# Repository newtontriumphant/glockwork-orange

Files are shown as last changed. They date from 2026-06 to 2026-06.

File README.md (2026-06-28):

# _Glockwork Orange_, by zsharpminor

A "Clockwork Orange" is defined as a human being who has had their free will and moral agency mechanically stripped away, turning them into a predictable, unthinking mechanism controlled by outside forces like the state. The human's natural "juicy" state is manifest in the orange, whereas the clockwork represents the unnaturality and cold predictability of the system.

Anyways, enough 1984; hiya! I'm Udo, better known as @zsharpminor or gh/newtontriumphant, and I have a thing for self-playing instruments. In late 2025, I won Honorable Mention at Hack Club x AMD's _Prototype_ flagship hackathon with [FiddleStein](https://github.com/newtontriumphant/Hackclub_Prototype_Fiddlestein), a fully self-playing violin that utilized a SO-101 robot arm and a 10k-step neural network to imitate a real human arm playing violin. FiddleStein was a great concept, but it sounded _mildly bad_, to be polite. Ever since early 2026, I wanted to create another self-playing instrument that would fit in well with FiddleStein, and Glockwork Orange was the logical next step.

## About Glockwork Orange

Glockwork Orange is a fully self-playing chromatic Glockenspiel that relies on solenoids to play ANY midi file payload by adjusting the instrumentation to fit into two voices!

> Sidenote: in the musical percussion and orchestra community, "glock" is used to abbreviate "glockenspiel" and is in no way related to the firearm brand created by Gaston Glock.

Glockwork Orange was designed for [Hack Club Outpost](https://outpost.hackclub.com/) as an X-Tier project, and is [on the list of X-Tier approved projects](https://docs.google.com/document/d/1faTrnYnGDMR5YSOkvKIAk_NsVOftPFZkB7XtJXA-l8c/edit?tab=t.0) sent out by [@CAN](https://hackclub.slack.com/archives/C0B519PGU22/p1781193322652829?thread_ts=1781016229.290339&cid=C0B519PGU22).

Anyways, enough yapping. A picture plays more than a thousand notes, or however the saying goes. Feast your eyes on the final assembled mockup of Glockwork Orange below.

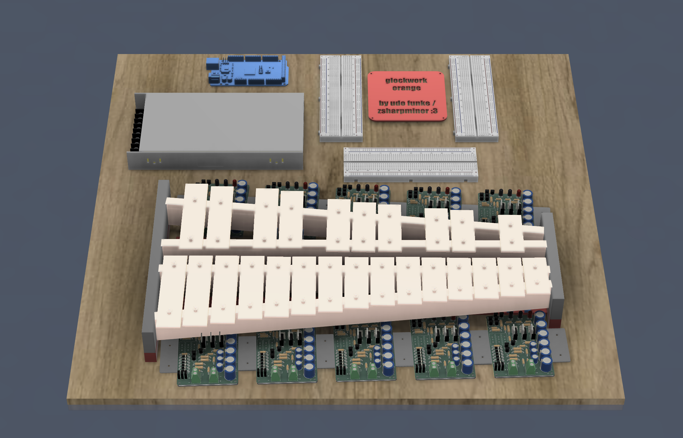
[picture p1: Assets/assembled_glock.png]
Assembled Glock

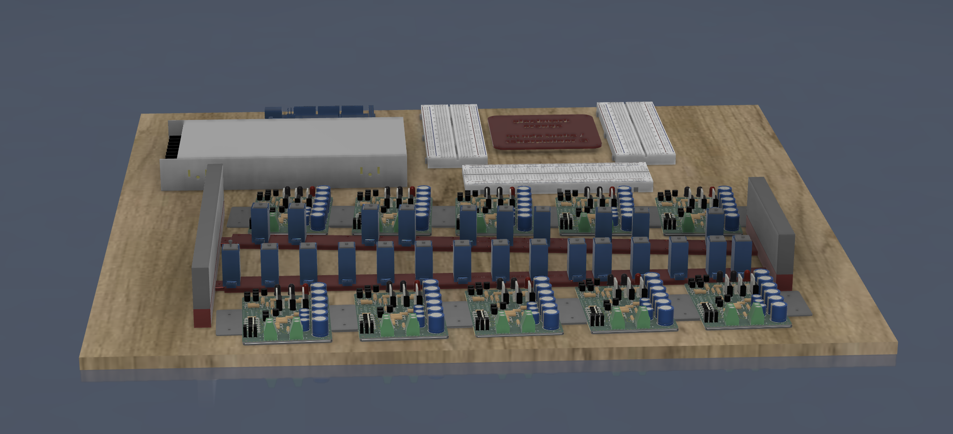
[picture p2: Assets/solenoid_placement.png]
Solenoid Placement


---

At this point, you're probably asking: **how does this lie-detector-looking-thing work?!&**

Well, it's quite simple.

1. The Arduino sends a logic signal to the PCB being striked.
2. The power supply pushes out 15V and routes it into the PCB chain.
3. The respective PCB converts that signal to the current and voltage required to operate the solenoids.
4. The MOSFET briefly powers the solenoid and, by extension, the LED.
5. The solenoid strikes the key and immediately retracts.
6. Repeat (but don't rinse. handwashing is very bad when it comes to PCBs)!

## The PCB

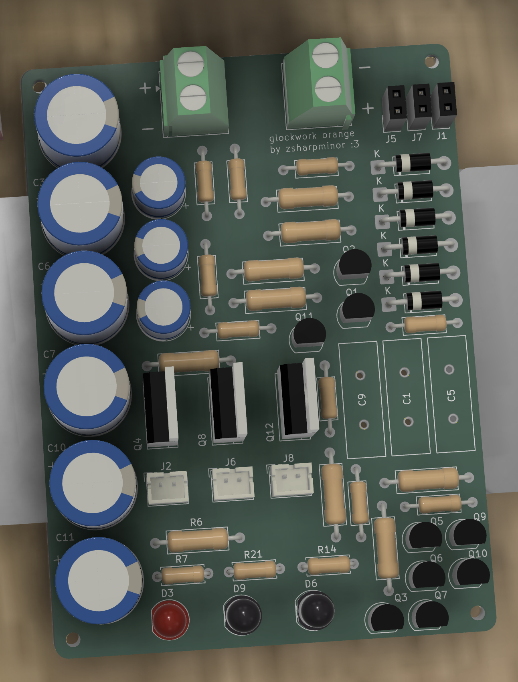
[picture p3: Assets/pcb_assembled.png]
The Assembled PCB


Glockwork Orange's PCB uses a clever arrangement of transistors, resistors, capacitors, and a MOSFET to power the white JST connectors and their respective fading red LEDs each time the individual MOSFET is triggered.

Oh? What do I hear? You're wondering how this monstrosity was wired? If you have any experience doing ground planes on PCBs, I'd recommend you avert your eyes.

fpcb

I've also included an image of the PCB's schematic:

schemfinal

The way this schematic works is by dividing the three inputs from the Arduino into segments, which each result in one JST connector and LED being powered at one time.

## The CAD

The way this project works is that it relies on the individual components being screwed down into a plywood project panel with M2 screws. That's why there's M2 screws on EVERY SINGLE COMPONENT in my CAD folder. 

For more information, including images and in-progress screenshots of every single CAD part, refer to [JOURNAL.md](JOURNAL.md). I won't entirely leave you hanging, though. Here's a side-view:

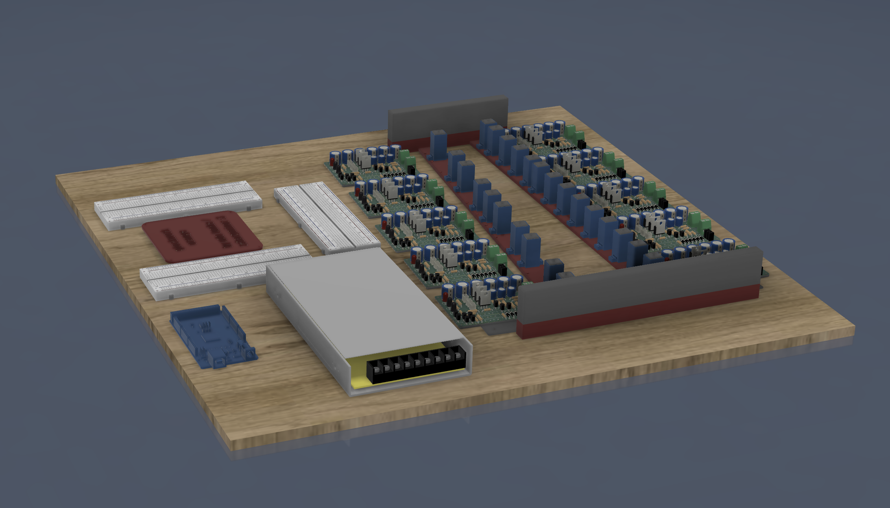
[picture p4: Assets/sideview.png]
side view of glock Side View of Glockwork Orange


The blue parts are the solenoid holders I designed, and they slot onto the red holder bar that I also designed. The grey parts inside the blue holders refer to the actual solenoids.

## Wiring Diagram

Please excuse ~~my dear aunt sally~~ the sloppy wiring, this is only supposed to be *representative* of the final wiring!

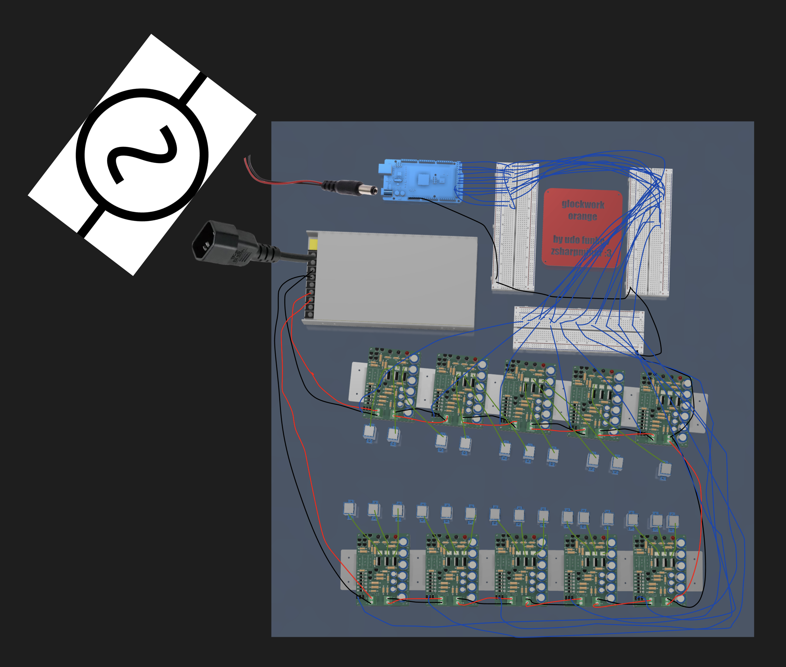
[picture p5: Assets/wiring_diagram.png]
wiring diagram Wiring Diagram


```
+15V --> Red
Shared GND --> Black
Solenoid +/- --> Green
Arduino Signal --> Blue
```

## Firmware

The Glockwork Orange firmware consists of two files: `glockwork_orange.ino`, which runs on the Arduino Mega 2560 and maps all 25 chromatic keys (G2–A4, MIDI 43–69) to digital pins 22–46 driving the IRLZ44N MOSFET gate lines, and `glockwork_host.py`, a Python/Tkinter desktop GUI that parses any MIDI file, re-voices it into two chromatic voices within the glockenspiel's range via octave-shifting, and streams precisely-timed strike commands over USB serial at 115200 baud. The Arduino firmware uses a non-blocking 32-slot ring buffer to schedule and execute 35ms solenoid pulses without any delay() calls, which means the timing is, dare I say so myself, quite accurate across simultaneous voices. The host communicates via a simple ASCII protocol (S to start, N{ms},{note} to schedule a strike, X to stop), making it straightforward to extend or replace the Python frontend with any serial-capable environment.

## The Why And The How

Why did I make Glockwork Orange? Well, this one's pretty simple. I always wanted to make a successor to FiddleStein, one that could permanently work and be mounted in place with actual PCBs rather than precarious wiring and hot glue. (Also, using it to get into Outpost was a pretty fun motivation!)

How did I make Glockwork Orange? The entire process is in [JOURNAL.md](JOURNAL.md). Go read it. No, seriously. A lot of research went into this project, and it's a culmination of thoughts and solenoids. TL;DR, the answer is Patience (and a lack thereof).

## Directory

```
.
├── Assets/ <-- Some of the most important images found in this README
├── CAD/ <-- All CAD source files, as well as a .f3z Archive
├── Firmware/ <-- Simple firmware for the Arduino
├── PCB/ <-- KiCad source files of the PCB, .STEP export of PCB
├── Production/ <-- Gerber files and zipped Gerber files
├── BOM.csv <-- All components required to build this monstrosity
├── JOURNAL.md <-- Detailed explanation and tracking of hours
└── README.md <-- This file!
```

## Mini BOM

**NOTE**: The full BOM is located at [BOM.csv](BOM.csv). PLEASE READ IT. THIS IS ONLY A BREAKDOWN.

**CART SCREENSHOTS** can be found in the [Assets/Cart-Screenshots](Assets/Cart-Screenshots/Digikey_Cart_Final.png) folder. PII has been redacted. If the originals are required, DM @zsharpminor on the Hack Club Slack.

| Item | Total | Link |
| :--- | ---: | :---: |
| DigiKey Components | $480.00 | [↗](BOM.csv) |
| Amazon Components | $122.00 | [↗](BOM.csv) |
| Plywood from THD | $15.00 | [↗](BOM.csv) |
| JLCPCB PCB x 10 | $15.00 | [↗](BOM.csv) |
| Arduino and PSU | **OWNED** | - |
| | **$632.00** | |

## Disclosure of AI Usage

No Artificial Intelligence was used in creating the PCB, Schematic, any of the CAD, or README / JOURNAL.

AI was solely used to automate placing links into the BOM (~10% of BOM tracked hours), and for minor assistance with the code (see bottom of [JOURNAL.md](JOURNAL.md) for additional information), and for creating a custom footprint for an obsolete capacitor.

## License

GNU General Public License (GPL)

---

Thanks for reading down all this way! If you have any questions, please reach out to me via the Hack Club Slack @zsharpminor

Made with ♡ by zsharpminor

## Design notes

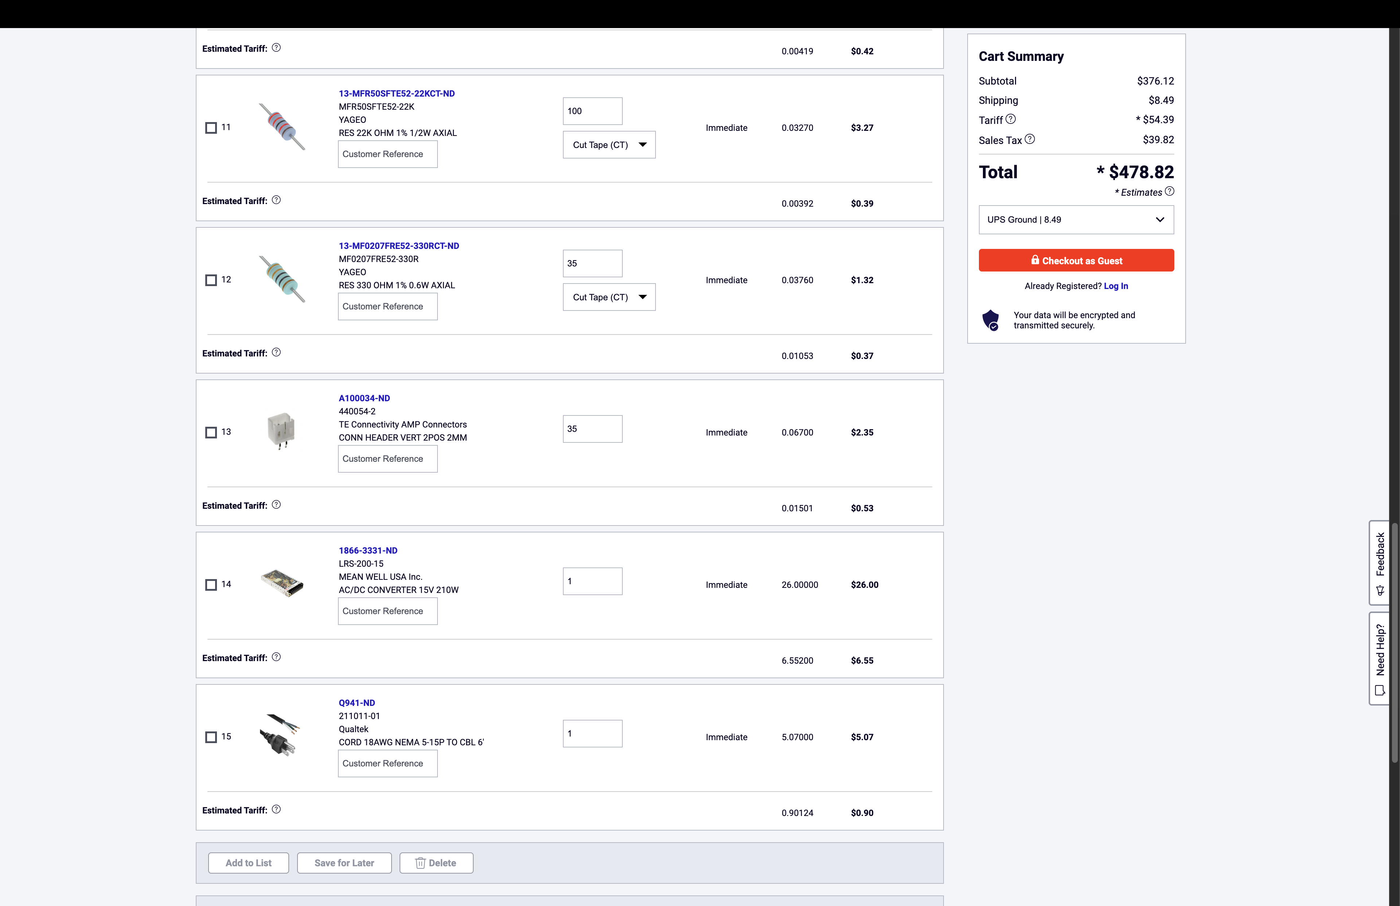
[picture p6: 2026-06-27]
Assets/Cart-Screenshots/Digikey_Cart_3.png

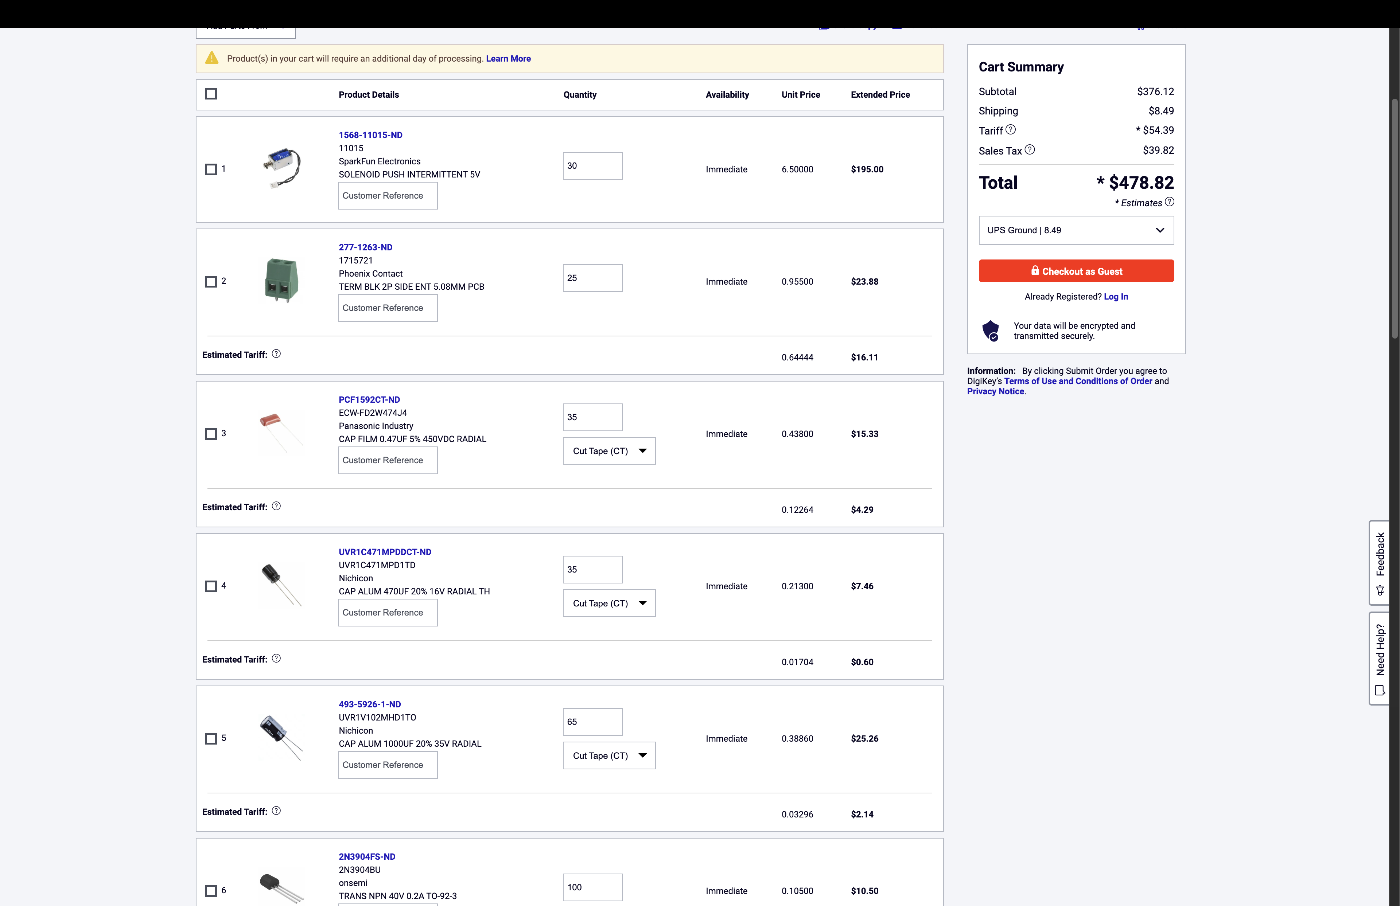
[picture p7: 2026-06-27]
Assets/Cart-Screenshots/Digikey_Cart_1.png

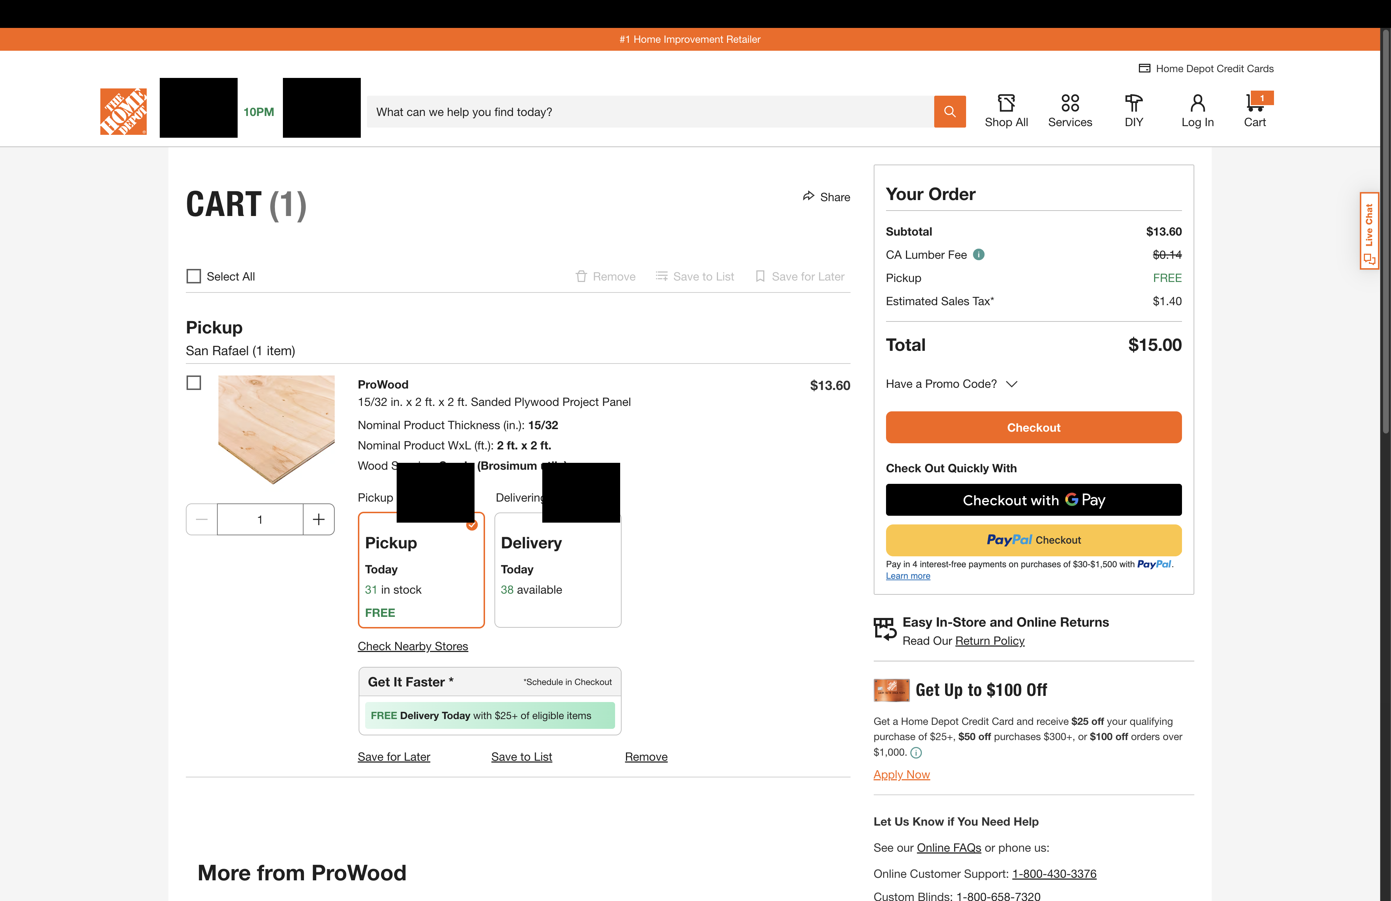
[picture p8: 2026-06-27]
Assets/Cart-Screenshots/The_Home_Depot_Cart.png

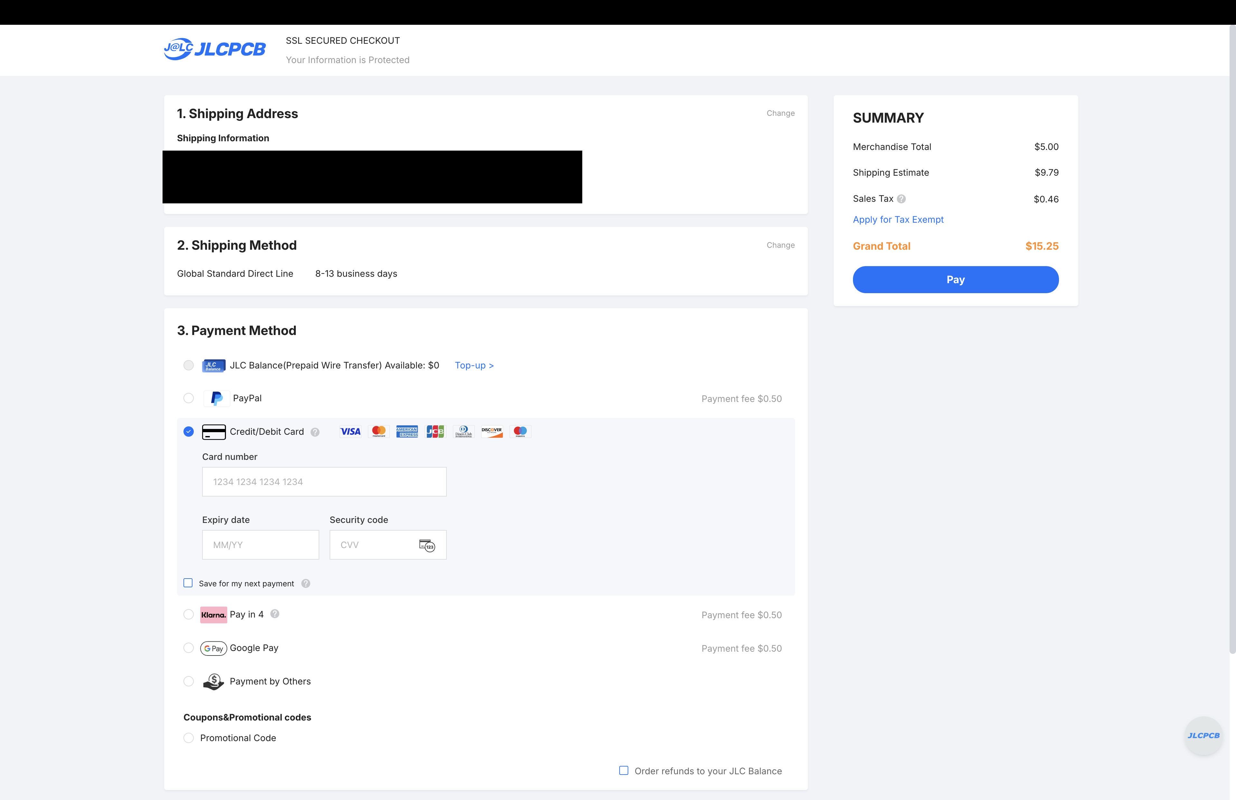
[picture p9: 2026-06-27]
Assets/Cart-Screenshots/JLC_Cart_1.png

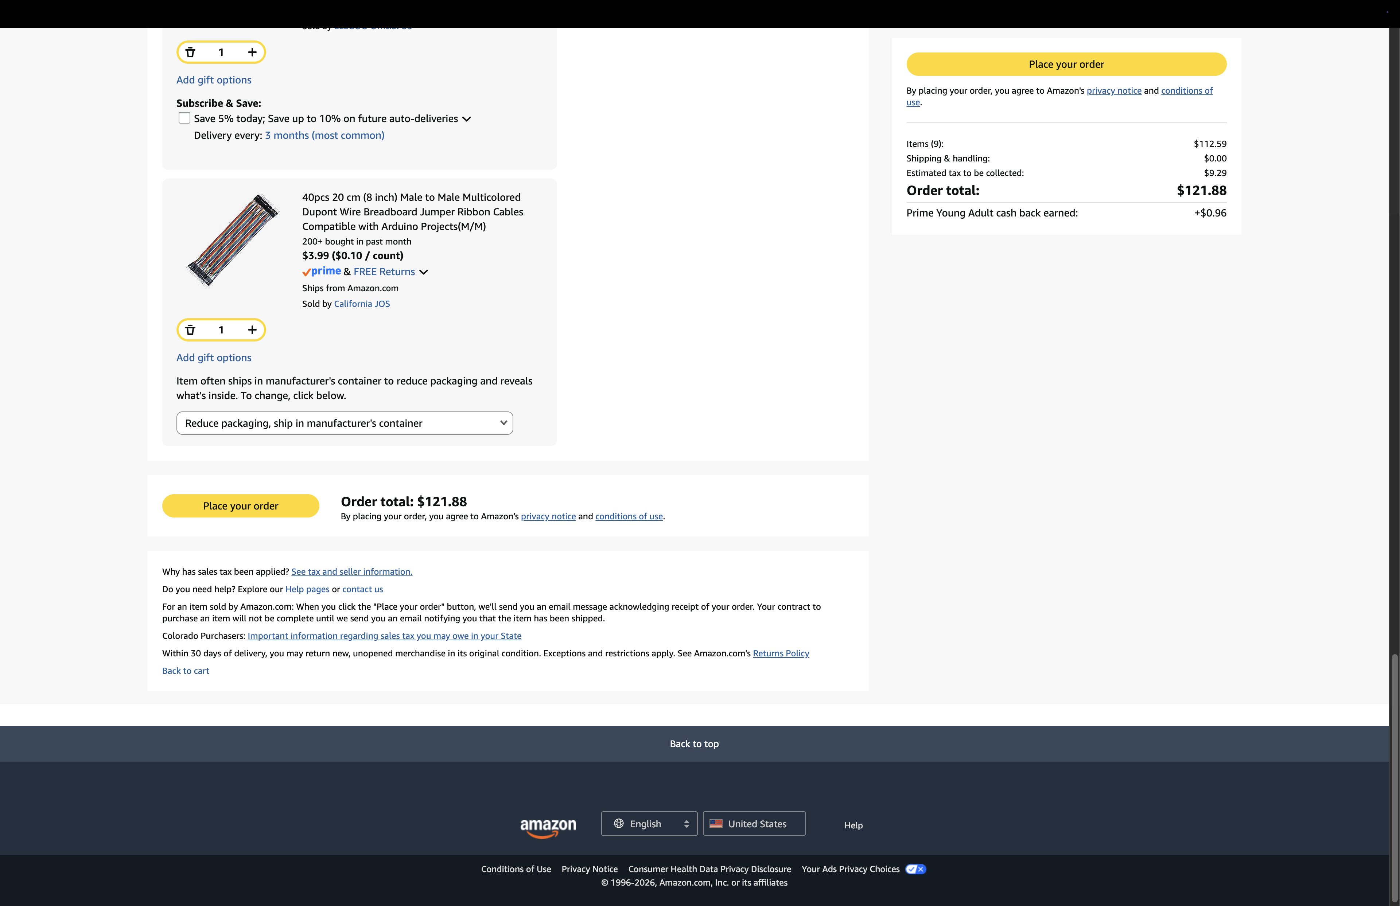
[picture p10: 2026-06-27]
Assets/Cart-Screenshots/Amazon_Cart_1.png

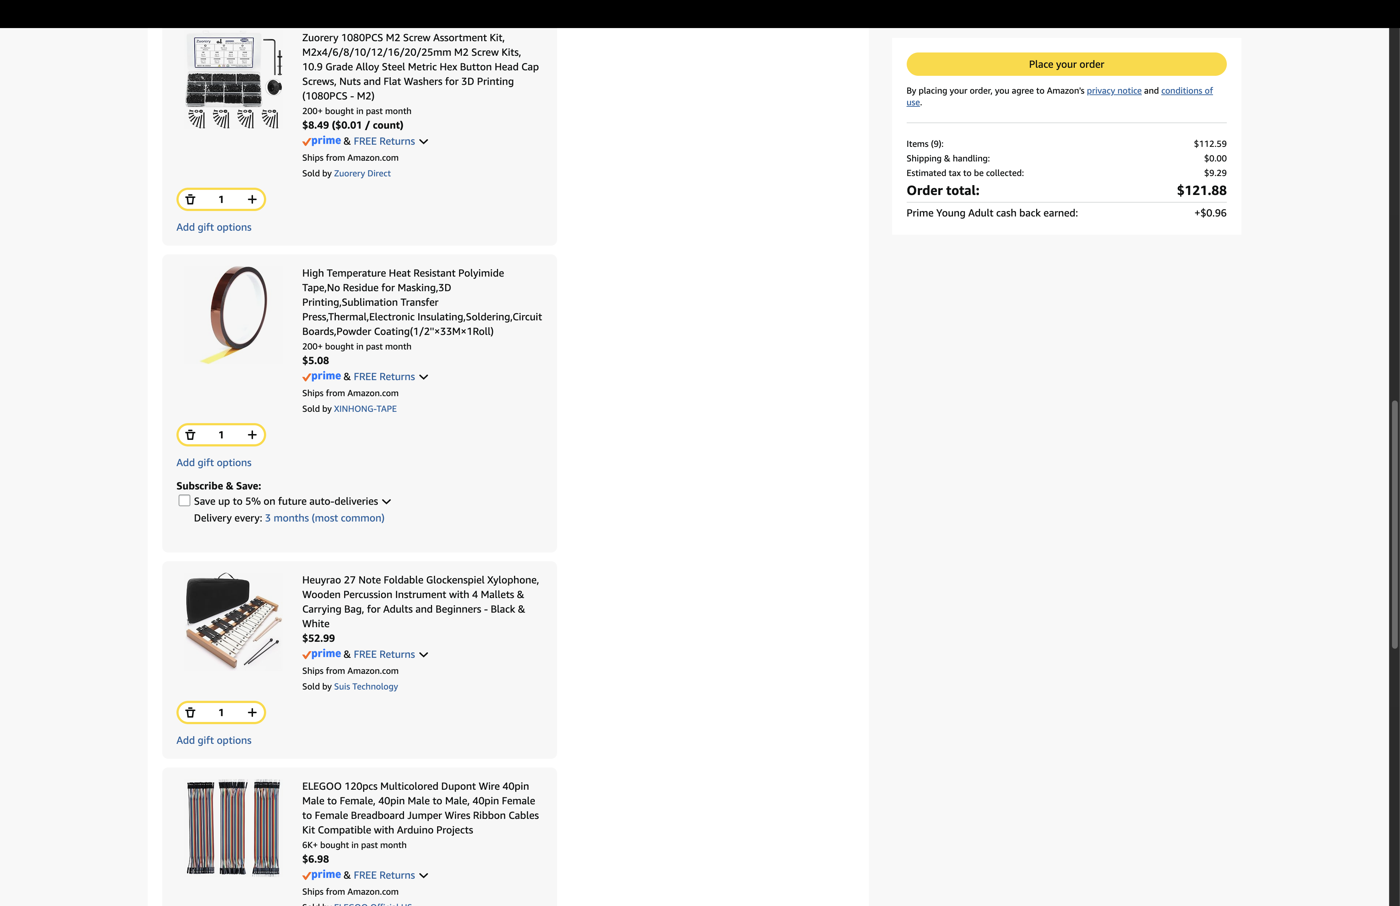
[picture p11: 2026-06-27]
Assets/Cart-Screenshots/Amazon_Cart_2.png

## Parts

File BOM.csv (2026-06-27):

Name | Source | Purpose | Cost Per | Quantity | Cost Total | Link
Terminal Block | Digikey | Input and Output for 15V + GND | $0.96 | 25 | $23.88 | https://www.digikey.com/en/products/detail/phoenix-contact/1715721/260631
5V Solenoid - Small | Digikey | The Glock Actuator | $6.50 | 30 | $195.00 | https://www.digikey.com/en/products/detail/sparkfun-electronics/ROB-11015/6163694
470nF Cap | Digikey | Capacitance | $0.44 | 35 | $15.33 | https://www.digikey.com/en/products/detail/panasonic-electronic-components/ECW-FD2W474J4/3844529
470uF Cap | Digikey | Capacitance | $0.21 | 35 | $7.46 | https://www.digikey.com/en/products/detail/nichicon/UVR1C471MPD1TD/3438545
1000uF Cap | Digikey | Capacitance | $0.39 | 65 | $25.29 | https://www.digikey.com/en/products/detail/nichicon/UVR1V102MHD1TO/3438559
2N3904BU | Digikey | Transistor | $0.11 | 100 | $10.50 | https://www.digikey.com/en/products/detail/onsemi/2N3904BU/1413
1N4007 | Digikey | Rectifier Diode - Current Backtrack Prevention | $0.05 | 100 | $5.40 | https://www.digikey.com/en/products/detail/diotec-semiconductor/1N4007/18833652
LED | Digikey | Diffused Red LED for Showcase Purposes | $0.15 | 35 | $5.08 | https://www.digikey.com/en/products/detail/kingbright/WP7113ID/1747663
MOSFET | Digikey | Toggling On High Current | $0.94 | 50 | $46.95 | https://www.digikey.com/en/products/detail/infineon-technologies/IRLZ44NPBF/811808
Resistor 2.2k | Digikey | Resistance | $0.03 | 100 | $3.30 | https://www.digikey.com/en/products/detail/yageo/MFR50SFTE52-2K2/9151337
Resistor 22k | Digikey | Resistance | $0.03 | 100 | $3.30 | https://www.digikey.com/en/products/detail/yageo/MFR50SFTE52-22K/9151275
Resistor 330 | Digikey | Resistance | $0.04 | 35 | $1.33 | https://www.digikey.com/en/products/detail/yageo/MF0207FRE52-330R/9124999
Solenoid Connector | Digikey | JST Connector for Solenoid | $0.07 | 35 | $2.35 | https://www.digikey.com/en/products/detail/te-connectivity-amp-connectors/440054-2/2077939
Power Cord | Digikey | Scary Wall Outlet ⟶ 3 cables | $5.07 | 1 | $5.07 | https://www.digikey.com/en/products/detail/qualtek/211011-01/5639882
Power Supply | Digikey | AC-DC 15V 210W (PSU) | $26.00 | 1 | $26.00 | https://www.digikey.com/en/products/detail/mean-well-usa-inc/LRS-200-15/7705023
Shipping | Digikey | FedEx Ground | $8.49 | 1 | $8.49 | https://www.digikey.com/ordering/shoppingcart
Tariff | Digikey | US Import Tariff (Estimated) | $54.39 | 1 | $54.39 | https://www.digikey.com/ordering/shoppingcart
Sales Tax | Digikey | I don’t want the IRS to send a bomb to my house /j | $39.82 | 1 | $39.82 | https://www.digikey.com/ordering/shoppingcart
 |  |  |  | subtotal: | $478.92
 |  |  |  | DIGIKEY BOM TOTAL: | $480.00
Arduino Mega 2560 | OWNED | The brains of the project! :D | N/A | 1 | N/A | OWNED
PSU for Arduino | OWNED | Power Supply For The Brain! | N/A | 1 | N/A | OWNED
Full Wood Glockenspiel | Amazon | It Loves Being Hit! Just like your mo- bad joke, sorry. | $52.99 | 1 | $52.99 | https://www.amazon.com/dp/B0F62YSCMV
Kapton Tape | Amazon | I don’t want to mess around with raw AC. | $5.08 | 1 | $5.08 | https://www.amazon.com/dp/B0DZCR4TKM
16AWG Combo Wire | Amazon | This connects the PCBs together! | $9.99 | 1 | $9.99 | https://www.amazon.com/dp/B0FPFXLMHT
Jumpers M-M | Amazon | This is used to connect the Arduino to the Breadboards | $3.99 | 1 | $3.99 | https://www.amazon.com/dp/B0BRTJQZRD
Jumpers M-F | Amazon | This is used to connect the Breadboards to the PCBs! | $6.98 | 1 | $6.98 | https://www.amazon.com/dp/B01EV70C78
M2 Plastic Screws | Amazon | Screws for everything NOT involving the plywood | $8.49 | 1 | $8.49 | https://www.amazon.com/dp/B0GKMVNG4D
M2 Wood Screws | Amazon | Screws for anything going INTO the plywood (self-tapping) | $5.99 | 1 | $5.99 | https://www.amazon.com/dp/B0CY986CCR
JST-PH Extension Cables | Amazon | The cables on the solenoids are only 6cm! | $9.54 | 2 | $19.08 | https://www.amazon.com/XUGERIP-Connector-Female-Connectors-Extension/dp/B0D9R21XYY
Sales Tax | Amazon | Again, I’m (usually) a law-abiding citizen. | $9.29 | 1 | $9.29 | https://www.amazon.com/checkout/
 |  |  |  | subtotal: | $121.88
 |  |  |  | AMAZON BOM TOTAL: | $122.00
Plywood Panel | The Home Depot | Mounting for the ENTIRE project! | $15.00 | 1 | $15.00 | https://www.homedepot.com/p/ProWood-15-32-in-x-2-ft-x-2-ft-Sanded-Plywood-Project-Panel-109118/202093832
PCB | JLCPCB | 10pcs (10 * 3 = 30 solenoids), plus shipping & tax | $15.25 | 1 | $15.25 | https://jlcpcb.com
 |  |  |  | subtotal: | $30.25
 |  |  |  | MISC BOM TOTAL: | $30.00
ABSOLUTE TOTAL:
$480.00 | (Digikey)
$122.00 | (Amazon)
$30.00 | (JLCPCB)
$632.00
CART SCREENSHOTS ARE | IN THE CART-SCREENSHOTS FOLDER.

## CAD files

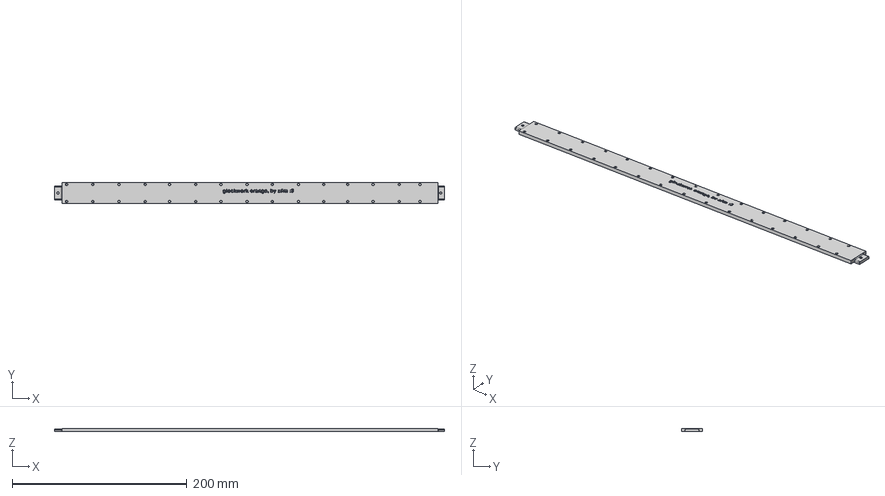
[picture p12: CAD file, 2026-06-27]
CAD/solenoid_bar.step
446.2 x 24.5 x 4.00 mm

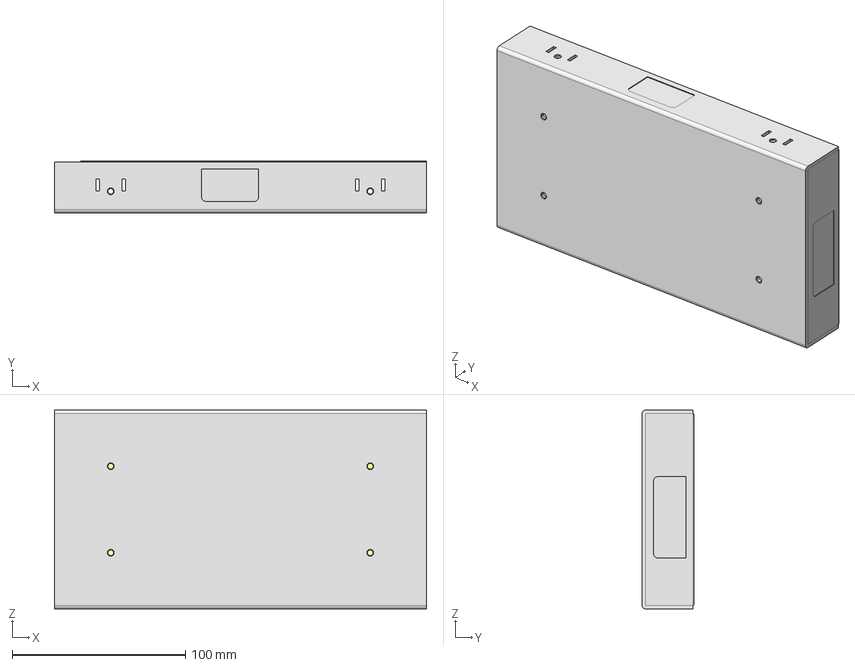
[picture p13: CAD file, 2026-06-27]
CAD/power_supply.step
215.0 x 30.0 x 115.0 mm

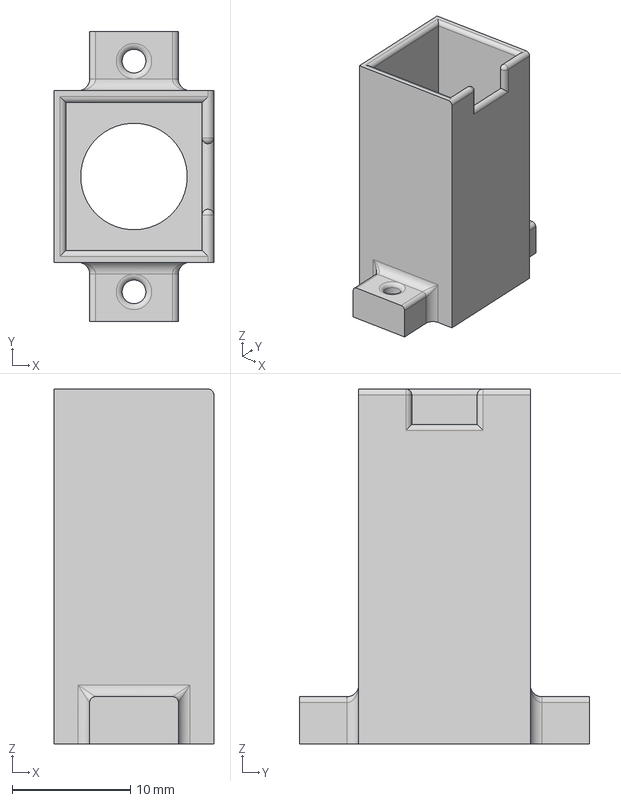
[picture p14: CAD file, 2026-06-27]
CAD/solenoid_holder.step
13.5 x 24.5 x 30.0 mm

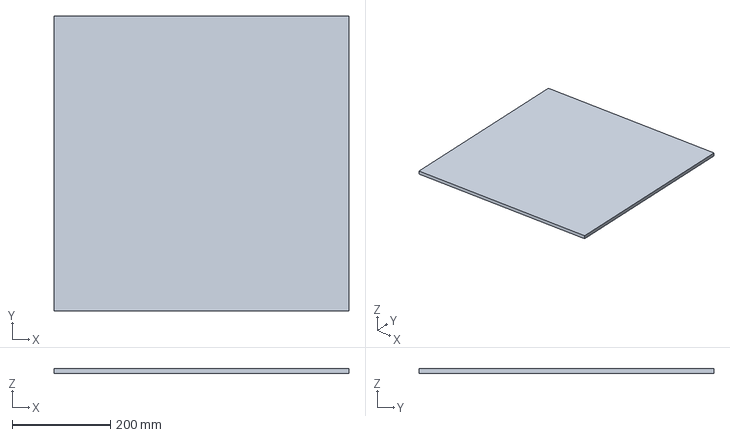
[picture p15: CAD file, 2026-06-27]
CAD/plywood.step
600.0 x 600.0 x 10.0 mm

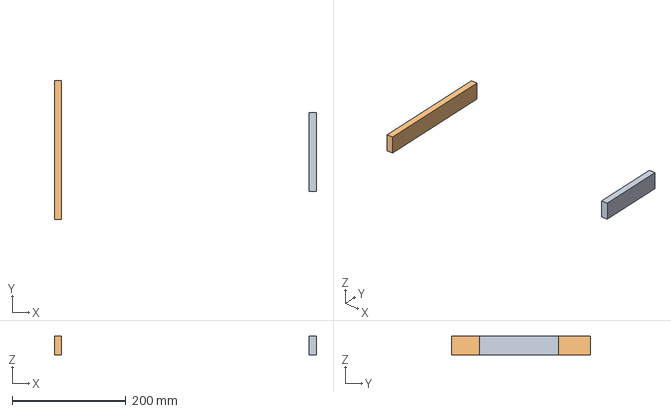
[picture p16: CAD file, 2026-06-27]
CAD/glockenspiel_stilts.step
460.0 x 244.7 x 33.0 mm

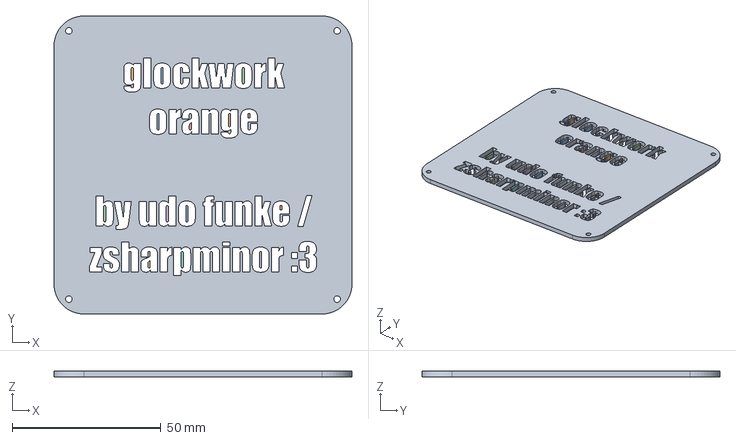
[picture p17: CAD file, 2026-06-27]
CAD/glockwork_logo.step
100.0 x 100.0 x 2.00 mm

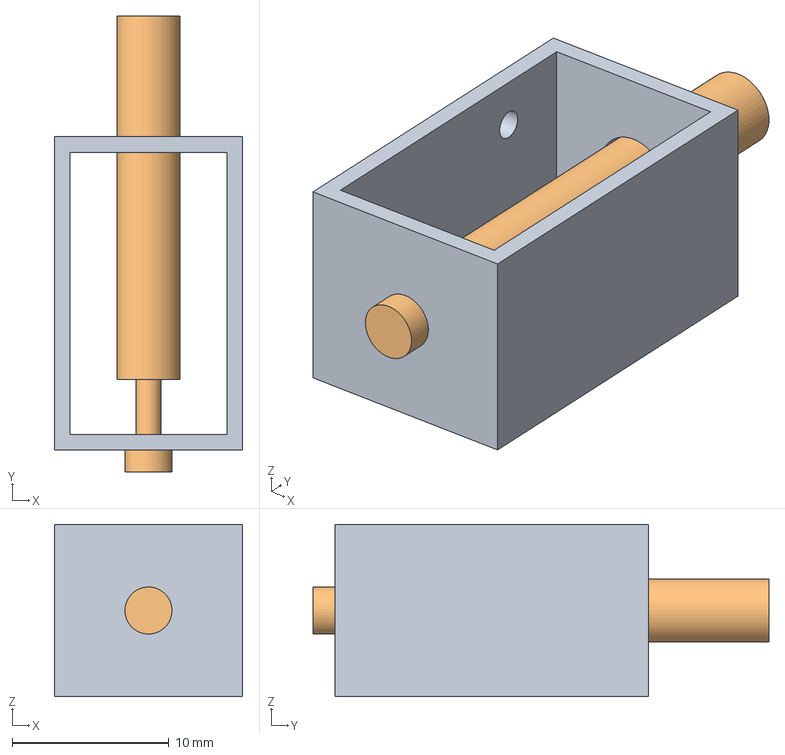
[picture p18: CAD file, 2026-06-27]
CAD/solenoid_model.step
12.0 x 29.1 x 11.0 mm

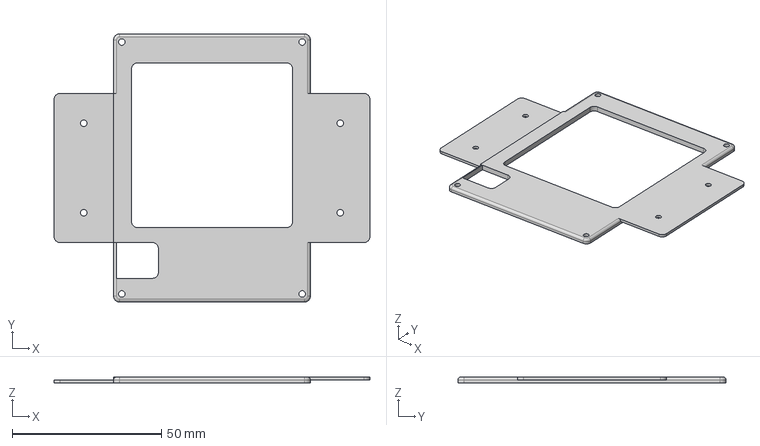
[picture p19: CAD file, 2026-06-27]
CAD/glockwork_pcb_holder.step
106.0 x 90.0 x 2.00 mm

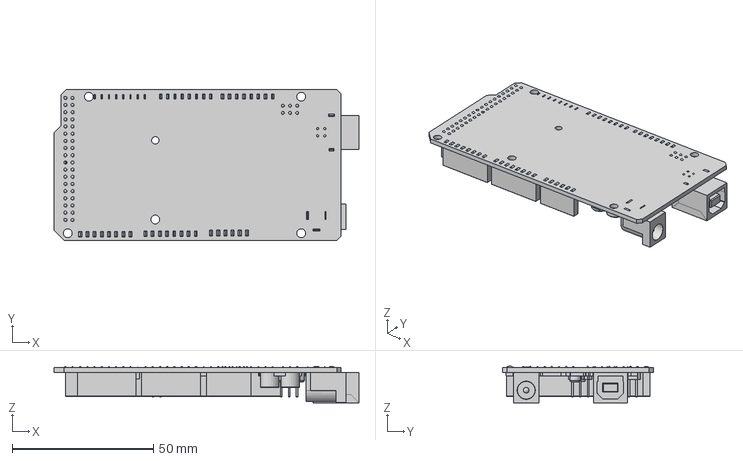
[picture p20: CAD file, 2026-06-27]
CAD/arduino_mega_2560.step
107.9 x 53.4 x 13.0 mm

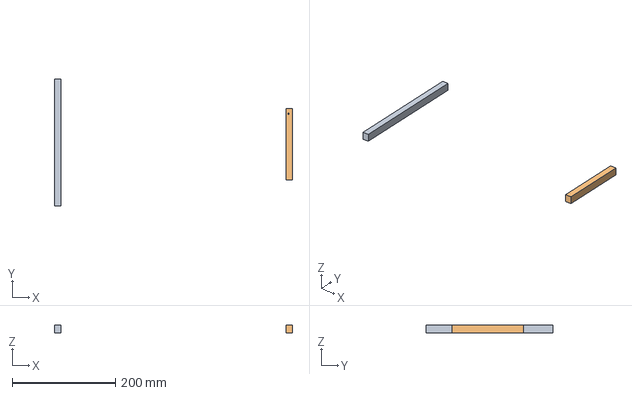
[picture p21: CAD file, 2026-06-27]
CAD/glockenspiel_screw_mounts.step
460.0 x 244.7 x 15.0 mm

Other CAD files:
CAD/glockenspiel_mesh.step

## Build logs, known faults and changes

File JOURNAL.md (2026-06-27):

Made by: @zsharpminor // gh/newtontriumphant // udo funke

Repository link: https://github.com/newtontriumphant/glockwork-orange/

Total hours so far: 22.0

# GLOCKWORK ORANGE - THE JOURNAL

gwofinal

## [06/13/26 | 2.0 hours]

### Ideation!

Hi and welcome! You're in for a long journ-ey (pun intended); this is where Glockwork Orange's ideation and development begins. After days of procrastinating starting this project, here we are. This is my Outpost project, it better be good.
I began by researching existing robot glockenspiel options, and came accross a [very interesting article](https://magazine.raspberrypi.com/articles/robot-glockenspiel) that had some great ideas. I didn't like the use of fragile lego parts, and felt that a PCB would work a crapton better than a breadboard, though. Additionally, I wanted Glockwork Orange to be chromatic and fully controllable via a desktop app - users should be able to upload ANY midi file and the app should smart-revoice it to be workable in two octaves with up to two voices.

### The Solenoid Hunt!

After I got the idea for my project, I began by researching **solenoids**. Having worked a bit with sols before, they're incredibly hard to work with, especially the sketchy ones you can get from AliExpress for borderline free. I would need a total of 25 (or more!) solenoids for this project, though, so I needed to compromise between quality and operation. I needed a solenoid that could work at a 5V baseline, would be small enough to fit DIRECTLY over the glock, and was cheap enough to order 25 of. I started at AliExpress, and was disappointed. [The cheapest option I could find](https://www.aliexpress.us/item/3256808985836089.html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) with at least 5mm travel and a small enough form factor was already $5.50, plus shipping.

This was a big issue, since I needed a solenoid with a consistent supplier and datasheet. I looked briefly on Alibaba, but the few I were able to find wanted MOQs of 1000 or more. I tried chatting with the sellers, but it was of no avail. Then, I stumbled accross a relatively reputable and consistent [solenoid sold by Sparkfun on behalf of Shenzhen Zonhen Electric Appliances Co., Ltd](https://www.sparkfun.com/solenoid-5v-small.html), a rather reputable Chinese solenoid company.

solenoid image

This solenoid had both a sufficient stroke (6mm), a small enough form factor (12x11mm!), and it could even run on 5V, meaning I didn't have to worry about 24V solenoid power supplies. Finally, it also had a [relatively good datasheet](https://cdn.sparkfun.com/datasheets/Robotics/ZHO-0420S-05A4.5%20SPECIFICATION.pdf), meaning it would be an excellent starting point for Glockwork Orange!

### The Glockenspiel Itself!

> Sidenote: in the musical percussion and orchestra community, "glock" is used to abbreviate "glockenspiel" and is in no way related to the firearm brand created by Gaston Glock.

You can't have a self-playing glock without the glock itself! I started by looking for glocks that already had 3D models available, and found to my dismay that the only available 3D models of glockenspiels were either paid or so low-quality that they didn't sufficiently resemble the real product. For that reason, I shifted approaches and asked myself: what's the cheapest glockenspiel that meets all of the criteria I needed (at least 25 keys, chromatic, top/bottom layout, real metal keys, flat) and would arrive reasonably quickly?

glock pun

(no, amazon, i do not want to buy a gun today, thank you very much)

Anyways, I found this [glockenspiel](https://www.amazon.com/Heuyrao-Glockenspiel-Xylophone-Professional-Instrument/dp/B0F62YSCMV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) that looked decent and [this 3D model](https://sketchfab.com/3d-models/metalofono-cromatico-25-notas-g2-a-g4-f864735df7be4f87af08a44f3913456a) that would work as a mockup! :D

glockenspiel 3d model

Now, onto the fun part: the 3D modeling of the solenoids! :)

## [06/17/26 | 3.0 hours]

### Research

This week, I began by emailing SparkFun about bulk pricing - and got a bit of a discount, saving over $10 on an order of 30 solenoids, which is pretty nice.

Then, I spent some time looking up existing projects, and besides the one I looked at last week, I found two very compelling candidates: https://www.instructables.com/Copper-Pipe-Auto-Glockenspiel/ and https://neil.fraser.name/hardware/glockenspiel/ - both of which used very similar solenoids, and one of which had the genius idea of implementing LEDs for the playing of the keys. This inspired me to add LEDs to my glockenspiel. Additionally, I found some issues, and made a:

### Checklist

- [x] Find a working solenoid
- [x] Find a working glockenspiel
- [ ] 3D model the solenoid holder
- [ ] Schematic for PCB
- [ ] Routing for PCB
- [ ] 3D model the glock holder
- [ ] Find a way to power the solenoids
- [ ] Write a compelling README
- [ ] ship :3

There may be a ways to go, but a good start for today would be to 3D model the solenoid holder and start the PCB schematic.

### 3D Modeling The Solenoid Holder

I began by looking at the datasheet for the specific solenoid I wanted to work with:

datasheet

My first thought? Not as complicated as I expected. The hardest part for me was figuring out which end of the solenoid was the business end.

> Spoiler alert: both ends move. In solenoids, the "striking" end is the end that doesn't have a spring and appears to be flatter. For my purposes, the spring end would have to be container by the holder, since the holder would be bottom-mounted in relation to the glock! :D

fusion bootup

I really need to learn how to use Onshape one of these days... Fusion is eating up my poor Mac's RAM :p

I started by creating a sketch using the datasheet's dimensions. Since it was quite the crappy datasheet, I had to estimate the spring's diameter.

sketch

Then, I extruded the solenoid holder, added a fillet, and space for the spring to go downward.

extrude1

The plan here is for the solenoid to be held down by a dab of hot glue on two corners. I also added a wire holder and some more fillets.

### 3D Modeling The Assembly (Part One!)

I wanted to have a rail that held the solenoids in place, but to get that to work I first needed a glockenspiel model.

It turns out, it's really hard to find a good glockenspiel model that isn't $30. Thankfully, I found this one:

og

It wasn't perfect, but it would do the job done. After a crap-ton of plane cutting and retexturing, I got a semi-decent version of it into Fusion:

infusion

This would work quite well for my purposes. Onto modeling the bar!

### 3D Modeling The Holder Bar

After some head-bangingly infuriating googles, I finally got a model of the solenoid and the model of the glockenspiel to scale. I also added bars on the sides:

bars

Then, I started working on the screws for the holder bar. I figured out that M2x8 and M2x10mm screws would work best for the non-chromatic and chromatic notes of the glock, respectively.

sketch

This might be a mild bit of chaos, but at least the proportions are right! Finally, the holder bar is ready to accept the holders.

holderbarsketch

It's been three hours now. I'm going to extrude this and take a break to play my *real* instrument of the violin. This is taking too long :p

Anyways, after some Fusion Magic™️ (and changing WAY too many lines to construction lines), enjoy the final extruded version of the holder bar:

final_bar

There's a bit of an offset issue - but that can easily be fixed later. See ya tonight! :D

- [x] 3D model the solenoid holder

## [06/24/26 | 4.0 hours]

### The PCB Schematic!

I've procrastinated this for wayy too long. After doing some intense research, I figured out it would be best if I used a 15V power supply and had 10 PCBs which each fed to 3 solenoids, for a total of 30 solenoids. For a 15V schematic, I need a boatload of 2N3904 transistors, though. Let's get to it!

schem1

I have a plan. It may not seem like it now, but I do. I promise :3

I then proceeded to spend an ENTIRE HOUR researching MOSFETs. No, I'm not joking. The original MOSFET I had thought of for this project was unfortunately discontinued and therefore way too expensive, but I found a pretty good drop-in replacement: the IRF530NPBF and IRLZ44NBPF would both be good options - the 530 would require a step-up, though, so I ultimately went with the IRLZ44N.

I also subtly stole the idea of having a hardware-coded flashing LED from [this project](https://engineering.tamu.edu/news/2019/05/the-autospiel-computer-engineering-students-merge-disciplines-to-automate-music.html). With that, the first draft of the schematic was done:

schem2

After running ERC and getting only the usual power pin not driven by output pin lines, I thought I was in the clear, until I double-checked the datasheets and realized I FORGOT the MOST IMPORTANT PART: the 15v net! Also, the capacitors. Caps will always be the death of me, but after some research (and quite a bit of asking Claude), I realized my mistake, and fixed the schematic fully:

schem3

After some quick copy-pasting, and the addition of mounting holes and screw terminals to infinitely combine multiple PCBs, I ended up with this (I also realized what PWR_FLAG is actually used for...):

schemfinal

### Assigning Footprints

I don't know why, but this is always my least favorite part of making a PCB. I usually have to do this like six or seven times over before I get it right, and this wasn't much of an exception: after forty minutes, I finally had a good assignment that I was happy with. Thankfully, I was able to copy and paste most of the footprints. This is also where I locked in M2 as my choice for screws!

footprints

(Yes, I had to make a custom footprint. I hate my wife.)

pcb1

Hey, that looks pretty decent. I'll get onto the PCB routing tomorrow! :D

## [06/25/26 | 4.0 hours]

### Routing...

I don't even want to describe the pain I'm going through. PCB routing will be the death of me.

p1

yes, I know this layout probably won't work. let my stupid brain at least prove it to myself

p2

hold up... maybe it will work after all! lemme fix up my drc and get my silkscreen non-conflicting:

drc

Okay, here's the final routing for now. I'm getting some other people to sanity check it, but for now, four hours later, the PCB is routed! :D

fpcb

pcb3d

Tomorrow, I can finally get all of this into CAD. :D

## [06/26/26 | 2.0 hours]

### Modeling the PCB Holders

pcbmodel

I began by exporting the PCB as a .STEP file and importing it into Fusion. I then took some measurements and began my work on the PCB holder (see above.) The PCB is going to be mounted to this holder with 4 M2 screws, and a crap ton of M2 screws will be used in this assembly. Since my PCB had some signal wires on the bottom, as well as some hefty MOSFET leads, I had to make some additional cutouts:

cutoutone

cutouttwo

Then, the PCB holder was done! I settled for an interlocking design so that I could keep rowing these together! :D

interlocking

The final PCB holder was as follows:

pcbholderfinal1

pcbholderfinal2

With that done, I was finally able to get over to the master assembly!

### Assembly, Part One

After about 30 minutes, I was able to get all the PCBs in place. My plan is to screw all of this into a plywood surface, maybe an old desk or a plywood panel, something like this:

plywoodpanel

Anyways, I need to find a model for that in Fusion. Before we get there, here's what I got so far:

assembled1

The plan here is to power everything with an Arduino Mega 2560 and have the cables routed underneath the PCBs, where there's some wiggle room in between the screw mounts and the plywood. The whole project is definitely coming back together now! Let me find that checklist that I put together a few days ago...

- [x] Find a working solenoid
- [x] Find a working glockenspiel
- [x] 3D model the solenoid holder
- [x] Schematic for PCB
- [x] Routing for PCB
- [ ] 3D model the glock holder
- [ ] Find a way to power the solenoids
- [ ] Write a compelling README
- [ ] ship :3

Well, hey, we're almost there! I also know just what I'll use for the power - I'm taking inspiration from a similar self-playing project that uses a [Meanwell AC/DC converter](https://www.digikey.com/en/products/detail/mean-well-usa-inc/LRS-200-15/7705023) as opposed to a bench power supply, and I think that it would look dope on a plywood panel, so I'm going for that. First thing tomorrow, I'm going to incorporate this into my design! Until next time! :D 

## [06/27/26 | 7.0 hours]

### Modeling the Plywood, Glock Holder, and PSU

The plywood was simple - Fusion appearances are great. I went with 60x60cm, which is the 24x24 inch format that can be found literally anywhere.

Then, I proceeded to grab the 3D models of the PSU, Arduino Mega 2560, and breadboards I was planning to use, and integrated them into the assembly as well:

assembled2

For the glockenspiel itself, my plan is to have it be screwed in from the bottom of the plywood with one really long M2 screw - I'm planning to drill small holes into the bottom wood of the glock itself and use a 3D printed spacer to better accomplish this:

spacer

The glockenspiel holder also slots in one of the slots of the solenoid bar (I also went ahead and populated the remaining solenoids that I had already modeled the holders for):

holderwithsolenoids

### Finalizing Assembly

After another 30 minutes, I was able to complete the assembly! Yay! Every pair of blue dots is a solenoid, and the plan is to have the power from the PSU chain on the PCBs, so the PSU can remain on the far left side of the plywood. As for the arduino, I'll be using standard jumpers that chain through breadboards. Could I have made some sort of flex PCB? Maybe, but it would have been extremely tedious to get all of those cables to fit well.

assemblyfinal1

Now that everything's done, it's time to transition to getting a polished README, getting all of my files set for submission, and making a BOM and wiring diagram.

### Wiring Diagram

Weird choice to do first, I know, but I want to get it out of the way.

I began by opening up a new Figma document and importing my assembly picture, minus the glockenspiel and plywood. I then drew the first set of lines, connecting the first PCB to the PSU.

wd1

After 20 minutes of drawing blue lines on a trackpad (my hand hurts), the (admittedly sloppy) wiring diagram was done. Well, it made sense in my head.

wdf

### CAD and Gerber Files

I want this repo to be extremely organized, so I'm going to be very organized with my file naming as well. To begin with, I reopened my PCB in KiCad and exported my Gerbers so that I could make a production folder for my repo.

exportgerbers

Well, that was easier than even I expected it to be!

gerbers

Now onto the CAD... the FUN STUFF! /j it's taking 30 seconds to EVEN PROCESS a single export i hate fusion, my poor m2 macbook air is burning hot to the touch :pf:

Anyways, after a literal 30 minutes of waiting, I was able to get all the files I needed. @/1mon confirmed that I didn't need .f3d files of every single component, only a .f3z of the assembly in addition to the .STEPs:

1moniloveyouyouresuchacutiepiefemboyplscmereandletmecuddleyoualsoifyouseethisdmmefemboyonslackpls

cadexports

### README

Onto The Readme! I'm just going to put an image or two here and you can check out the commit diff for what was changed. TL;DR, added screenshots of files and explained basically everything in this JOUNRAL! :D

Here's a picture in-progress:

readme1

I also made a cool directory showcasing this repo off:

readme2

### BOM

Okay, this part is going to take a WHILE. 

I'm taking some inspiration from other projects I've seen, but mostly, all I need is a Glockenspiel, a piece of plywood, some cables, and a crap-ton of electronics.

Plywood panels are always fun to look at, and I went with the cheapest one that didn't look like it came off the back of an IKEA bunk bed:

plywood

Here's a sneak peak at the BOM so far:

bom1

This is gonna get really expensive really quickly...

Anyways, I did not use ANY AI for this project, except for finding a good transistor and capacitor, so now it finally gets to be used:

comet

Oh, how I love Perplexity Comet's "free" trial... anyways, for legal purposes I'm definitely doing nothing illegal at all.

Okay, the BOM is done. I feel bad for the Outpost team... I wonder if this'll get approved. I hope they weren't joking with the $1000 max funding!

P.S. When I say I spent seven hours on this project today, I'm not joking. I started this at 8:12 AM and it's already (SOMEHOW) 3:20 PM! If you doubt me, check the times all of the screenshots were taken (it's in the CDN name!)

The BOM itself took me TWO HOURS!

### Firmware

I'm going to use a simple Python GUI and `mido` as well as `pyserial` to interface with the Arduino's `ino` code.

code1

At its heart, the code is really simple, all it does is define the keys in an array and define a StrikeEvent that sends a signal to the MOSFET.

**PLEASE NOTE**: The Python GUI code is partially AI-assisted. I have tested it to the best of my ability and it works, but once I receive the PCB I will make major tweaks to this firmware. Thanks!

### The End?

[cue Minecraft Achievement]

It's definitely far from the end, as I'll probably spend about 50 hours actually building this, rewriting the firmware once I realize that the PCB doesn't work as expected, and redoing one or two CAD pieces because I didn't get the dimensions accurate enough.

Until then, farewell. sharp out >:3c

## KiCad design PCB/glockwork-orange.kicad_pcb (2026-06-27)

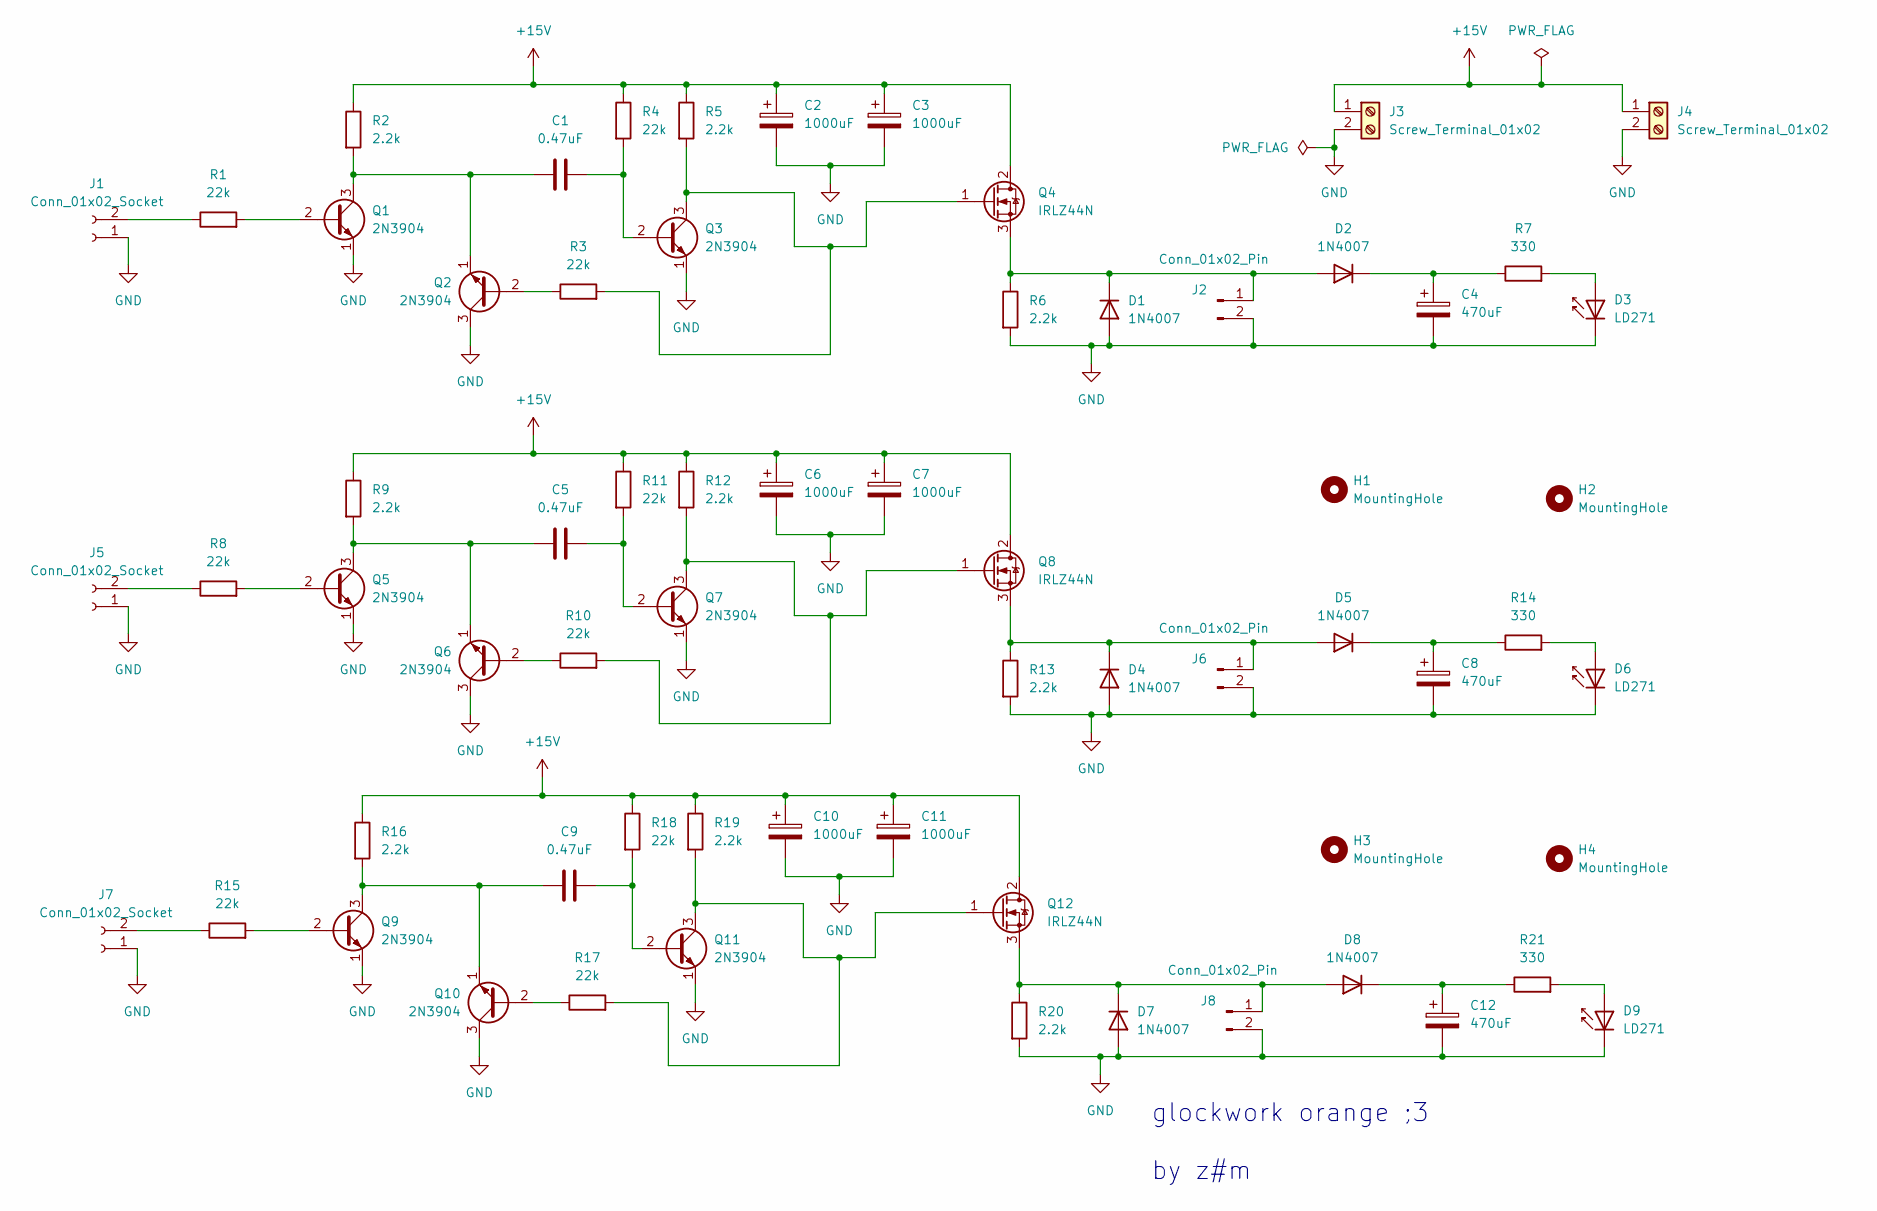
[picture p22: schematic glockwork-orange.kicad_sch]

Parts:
C1, C5, C9: 0.47uF; CAPRR750W80L1750T580H1400
C2, C3, C6, C7, C10, C11: 1000uF; CP_Radial_D12.5mm_P5.00mm
C4, C8, C12: 470uF; CP_Radial_D8.0mm_P3.50mm
D1, D2, D4, D5, D7, D8: 1N4007; D_DO-41_SOD81_P10.16mm_Horizontal
D3: LD271; LED_D5.0mm
D6, D9: LD271; LED_D5.0mm_IRGrey
H1, H2, H3, H4: MountingHole; MountingHole_2.2mm_M2
J1, J5, J7: Conn_01x02_Socket; PinSocket_1x02_P2.54mm_Vertical
J2, J6, J8: Conn_01x02_Pin; JST_PH_B2B-PH-K_1x02_P2.00mm_Vertical
J3, J4: Screw_Terminal_01x02; TerminalBlock_Phoenix_MKDS-1,5-2-5.08_1x02_P5.08mm_Horizont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
Q1, Q2, Q3, Q5, Q6, Q7, Q9, Q10, Q11: 2N3904; TO-92_Inline
Q4, Q8, Q12: IRLZ44N; TO-220-3_Vertical
R1, R3, R4, R8, R10, R11, R15, R17, R18: 22k; R_Axial_DIN0207_L6.3mm_D2.5mm_P10.16mm_Horizontal
R2, R5, R6, R9, R12, R13, R16, R19, R20: 2.2k; R_Axial_DIN0309_L9.0mm_D3.2mm_P12.70mm_Horizontal
R7, R14, R21: 330; R_Axial_DIN0207_L6.3mm_D2.5mm_P7.62mm_Horizontal

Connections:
+15V: C2.1, C3.1, C6.1, C7.1, C10.1, C11.1, J3.1, J4.1, Q4.2 (D), Q8.2 (D), Q12.2 (D), R2.1, R4.1, R5.1, R9.1, R11.1, R12.1, R16.1, R18.1, R19.1
GND: C2.2, C3.2, C4.2, C6.2, C7.2, C8.2, C10.2, C11.2, C12.2, D1.2 (A), D3.1 (K), D4.2 (A), D6.1 (K), D7.2 (A), D9.1 (K), J1.1, J2.2, J3.2, J4.2, J5.1, J6.2, J7.1, J8.2, Q1.1 (E), Q2.3 (C), Q3.1 (E), Q5.1 (E), Q6.3 (C), Q7.1 (E), Q9.1 (E), Q10.3 (C), Q11.1 (E), R6.2, R13.2, R20.2
unnamed: D1.1 (K), D2.2 (A), J2.1, Q4.3 (S), R6.1
unnamed: C4.1, D2.1 (K), R7.1
unnamed: D3.2 (A), R7.2
unnamed: D4.1 (K), D5.2 (A), J6.1, Q8.3 (S), R13.1
unnamed: C8.1, D5.1 (K), R14.1
unnamed: D6.2 (A), R14.2
unnamed: D7.1 (K), D8.2 (A), J8.1, Q12.3 (S), R20.1
unnamed: C12.1, D8.1 (K), R21.1
unnamed: D9.2 (A), R21.2
unnamed: J1.2, R1.1
unnamed: J5.2, R8.1
unnamed: J7.2, R15.1
unnamed: Q1.2 (B), R1.2
unnamed: C1.1, Q1.3 (C), Q2.1 (E), R2.2
unnamed: Q2.2 (B), R3.1
unnamed: C1.2, Q3.2 (B), R4.2
unnamed: Q3.3 (C), Q4.1 (G), R3.2, R5.2
unnamed: Q5.2 (B), R8.2
unnamed: C5.1, Q5.3 (C), Q6.1 (E), R9.2
unnamed: Q6.2 (B), R10.1
unnamed: C5.2, Q7.2 (B), R11.2
unnamed: Q7.3 (C), Q8.1 (G), R10.2, R12.2
unnamed: Q9.2 (B), R15.2
unnamed: Q10.2 (B), R17.1
unnamed: C9.1, Q9.3 (C), Q10.1 (E), R16.2
unnamed: C9.2, Q11.2 (B), R18.2
unnamed: Q11.3 (C), Q12.1 (G), R17.2, R19.2

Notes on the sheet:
glockwork orange ;3 by z#m

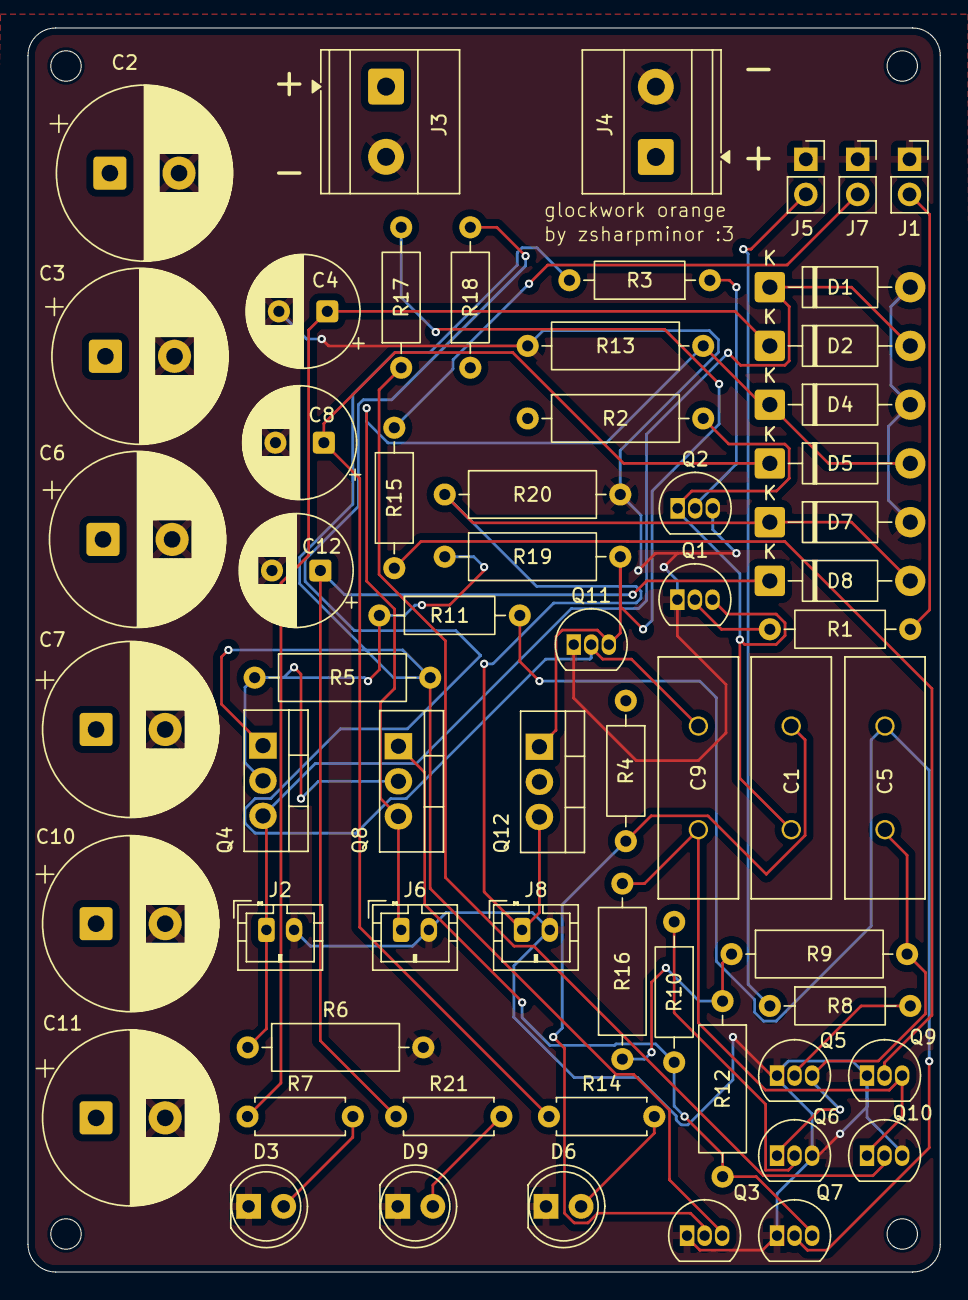
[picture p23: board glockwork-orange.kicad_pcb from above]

Board: 2 copper layers, 66.0 x 90.0 mm, 66 parts (0 on the bottom side), 29 nets.

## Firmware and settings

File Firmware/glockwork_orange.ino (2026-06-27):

#include <Arduino.h>

#define NUM_KEYS 25
#define SOLENOID_ON_MS 35
#define SERIAL_BAUD 115200

static const uint8_t KEY_PINS[NUM_KEYS] = {
    22, 23, 24, 25, 26, 27, 28, 29,
    30, 31, 32, 33, 34, 35, 36, 37,
    38, 39, 40, 41, 42, 43, 44, 45,
    46
};

static const uint8_t KEY_MIDI[NUM_KEYS] = {
    43, 44, 45, 46, 47, 48, 49, 50,
    51, 52, 53, 54, 55, 56, 57, 58,
    59, 60, 61, 62, 63, 64, 65, 66,
    69
};

struct StrikeEvent {
    unsigned long fire_at_ms;
    uint8_t pin;
    bool active;
};

static StrikeEvent queue[32];
static uint8_t queue_head = 0;
static uint8_t queue_tail = 0;

static unsigned long session_start_ms = 0;
static bool session_active = false;

static int8_t midi_to_key_index(uint8_t note) {
    for (uint8_t i = 0; i < NUM_KEYS; i++) {
        if (KEY_MIDI[i] == note) return (int8_t)i;
    }
    return -1;
}

static void enqueue_strike(uint8_t pin, unsigned long fire_at_ms) {
    uint8_t next = (queue_tail + 1) & 31;
    if (next == queue_head) return;
    queue[queue_tail].pin = pin;
    queue[queue_tail].fire_at_ms = fire_at_ms;
    queue[queue_tail].active = false;
    queue_tail = next;
}

static void process_queue(unsigned long now_ms) {
    uint8_t i = queue_head;
    while (i != queue_tail) {
        StrikeEvent &ev = queue[i];
        if (!ev.active && now_ms >= ev.fire_at_ms) {
            digitalWrite(ev.pin, HIGH);
            ev.active = true;
            ev.fire_at_ms = now_ms + SOLENOID_ON_MS;
        } else if (ev.active && now_ms >= ev.fire_at_ms) {
            digitalWrite(ev.pin, LOW);
            if (i == queue_head) {
                queue_head = (queue_head + 1) & 31;
            }
        }
        i = (i + 1) & 31;
    }
}

static void parse_command(const char *buf) {
    if (buf[0] == 'S') {
        session_start_ms = millis();
        session_active = true;
        Serial.println("OK_START");
        return;
    }
    if (buf[0] == 'X') {
        session_active = false;
        for (uint8_t i = 0; i < NUM_KEYS; i++) {
            digitalWrite(KEY_PINS[i], LOW);
        }
        queue_head = 0;
        queue_tail = 0;
        Serial.println("OK_STOP");
        return;
    }
    if (buf[0] == 'N') {
        if (!session_active) {
            Serial.println("ERR_NO_SESSION");
            return;
        }
        uint32_t offset_ms = 0;
        uint8_t note = 0;
        const char *p = buf + 1;
        while (*p >= '0' && *p <= '9') {
            offset_ms = offset_ms * 10 + (*p - '0');
            p++;
        }
        if (*p != ',') {
            Serial.println("ERR_BAD_CMD");
            return;
        }
        p++;
        while (*p >= '0' && *p <= '9') {
            note = note * 10 + (*p - '0');
            p++;
        }
        int8_t idx = midi_to_key_index(note);
        if (idx < 0) {
            Serial.println("ERR_NOTE_OOR");
            return;
        }
        unsigned long fire_at = session_start_ms + (unsigned long)offset_ms;
        enqueue_strike(KEY_PINS[idx], fire_at);
        Serial.println("OK_N");
        return;
    }
    if (buf[0] == 'P') {
        if (!session_active) {
            Serial.println("ERR_NO_SESSION");
            return;
        }
        uint8_t note = 0;
        const char *p = buf + 1;
        while (*p >= '0' && *p <= '9') {
            note = note * 10 + (*p - '0');
            p++;
        }
        int8_t idx = midi_to_key_index(note);
        if (idx < 0) {
            Serial.println("ERR_NOTE_OOR");
            return;
        }
        enqueue_strike(KEY_PINS[idx], millis());
        Serial.println("OK_P");
        return;
    }
    if (buf[0] == '?') {
        Serial.print("GLOCKWORK_ORANGE v1.0 KEYS=25 BAUD=");
        Serial.println(SERIAL_BAUD);
        return;
    }
    Serial.println("ERR_UNKNOWN");
}

static char rx_buf[64];
static uint8_t rx_pos = 0;

void setup(void) {
    Serial.begin(SERIAL_BAUD);
    for (uint8_t i = 0; i < NUM_KEYS; i++) {
        pinMode(KEY_PINS[i], OUTPUT);
        digitalWrite(KEY_PINS[i], LOW);
    }
    queue_head = 0;
    queue_tail = 0;
    session_active = false;
}

void loop(void) {
    unsigned long now = millis();
    process_queue(now);

    while (Serial.available()) {
        char c = (char)Serial.read();
        if (c == '\n' || c == '\r') {
            if (rx_pos > 0) {
                rx_buf[rx_pos] = '\0';
                parse_command(rx_buf);
                rx_pos = 0;
            }
        } else if (rx_pos < 63) {
            rx_buf[rx_pos++] = c;
        }
    }
}

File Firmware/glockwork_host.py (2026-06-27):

import tkinter as tk
from tkinter import filedialog, messagebox, ttk
import threading
import serial
import serial.tools.list_ports
import mido
import time
import os

BAUD_RATE = 115200
SOLENOID_RANGE_LOW = 43
SOLENOID_RANGE_HIGH = 69
TOTAL_RANGE = SOLENOID_RANGE_HIGH - SOLENOID_RANGE_LOW

def find_ports():
    return [p.device for p in serial.tools.list_ports.comports()]

def clamp_note_to_range(note):
    while note < SOLENOID_RANGE_LOW:
        note += 12
    while note > SOLENOID_RANGE_HIGH:
        note -= 12
    return note

def extract_voices(midi_path, max_voices=2):
    mid = mido.MidiFile(midi_path)
    tpb = mid.ticks_per_beat
    tempo = 500000

    raw_events = []
    for track in mid.tracks:
        abs_tick = 0
        for msg in track:
            abs_tick += msg.time
            if msg.type == "set_tempo":
                tempo = msg.tempo
            if msg.type == "note_on" and msg.velocity > 0:
                time_sec = mido.tick2second(abs_tick, tpb, tempo)
                raw_events.append((time_sec, msg.note, msg.velocity))

    raw_events.sort(key=lambda e: e[0])

    voice_last_time = [None] * max_voices
    scheduled = []

    for t, note, vel in raw_events:
        mapped = clamp_note_to_range(note)
        assigned = False
        for v in range(max_voices):
            if voice_last_time[v] is None or (t - voice_last_time[v]) >= 0.08:
                voice_last_time[v] = t
                scheduled.append((t, mapped))
                assigned = True
                break
        if not assigned:
            oldest = min(range(max_voices), key=lambda v: voice_last_time[v])
            if (t - voice_last_time[oldest]) >= 0.04:
                voice_last_time[oldest] = t
                scheduled.append((t, mapped))

    scheduled.sort(key=lambda e: e[0])
    return scheduled

class GlockworkApp(tk.Tk):
    def __init__(self):
        super().__init__()
        self.title("Glockwork Orange — Firmware Controller")
        self.geometry("600x480")
        self.resizable(False, False)
        self.configure(bg="#1a1a1a")

        self.ser = None
        self.playback_thread = None
        self.stop_event = threading.Event()
        self.midi_path = None
        self.scheduled_events = []

        self._build_ui()
        self._refresh_ports()

    def _build_ui(self):
        top = tk.Frame(self, bg="#1a1a1a", pady=12)
        top.pack(fill="x", padx=20)

        tk.Label(top, text="Glockwork Orange", font=("Courier", 18, "bold"),
                 bg="#1a1a1a", fg="#f5a623").pack(side="left")
        tk.Label(top, text="v1.0", font=("Courier", 10),
                 bg="#1a1a1a", fg="#666666").pack(side="left", padx=8, pady=6)

        port_row = tk.Frame(self, bg="#1a1a1a")
        port_row.pack(fill="x", padx=20, pady=4)

        tk.Label(port_row, text="Port:", font=("Courier", 11),
                 bg="#1a1a1a", fg="#cccccc", width=6, anchor="w").pack(side="left")

        self.port_var = tk.StringVar()
        self.port_menu = ttk.Combobox(port_row, textvariable=self.port_var,
                                       font=("Courier", 11), width=28, state="readonly")
        self.port_menu.pack(side="left", padx=4)

        tk.Button(port_row, text="Refresh", font=("Courier", 10),
                  bg="#2a2a2a", fg="#cccccc", relief="flat", bd=0,
                  activebackground="#3a3a3a", activeforeground="#ffffff",
                  command=self._refresh_ports, padx=8, pady=4).pack(side="left", padx=4)

        self.connect_btn = tk.Button(port_row, text="Connect", font=("Courier", 10),
                                      bg="#f5a623", fg="#1a1a1a", relief="flat", bd=0,
                                      activebackground="#d4891a", activeforeground="#1a1a1a",
                                      command=self._toggle_connect, padx=12, pady=4)
        self.connect_btn.pack(side="left", padx=4)

        self.status_dot = tk.Label(port_row, text="●", font=("Courier", 14),
                                    bg="#1a1a1a", fg="#555555")
        self.status_dot.pack(side="left", padx=8)

        file_row = tk.Frame(self, bg="#1a1a1a")
        file_row.pack(fill="x", padx=20, pady=8)

        tk.Label(file_row, text="MIDI:", font=("Courier", 11),
                 bg="#1a1a1a", fg="#cccccc", width=6, anchor="w").pack(side="left")

        self.file_label = tk.Label(file_row, text="No file selected",
                                    font=("Courier", 10), bg="#1a1a1a", fg="#666666",
                                    anchor="w", width=36)
        self.file_label.pack(side="left")

        tk.Button(file_row, text="Browse", font=("Courier", 10),
                  bg="#2a2a2a", fg="#cccccc", relief="flat", bd=0,
                  activebackground="#3a3a3a", activeforeground="#ffffff",
                  command=self._browse_midi, padx=8, pady=4).pack(side="left", padx=4)

        info_frame = tk.Frame(self, bg="#242424", bd=0, relief="flat")
        info_frame.pack(fill="x", padx=20, pady=4)

        self.info_label = tk.Label(info_frame, text="Load a MIDI file to see event summary.",
                                    font=("Courier", 10), bg="#242424", fg="#888888",
                                    anchor="w", padx=10, pady=8, justify="left")
        self.info_label.pack(fill="x")

        ctrl_row = tk.Frame(self, bg="#1a1a1a")
        ctrl_row.pack(fill="x", padx=20, pady=12)

        self.play_btn = tk.Button(ctrl_row, text="Play", font=("Courier", 13, "bold"),
                                   bg="#27ae60", fg="#ffffff", relief="flat", bd=0,
                                   activebackground="#1e8449", activeforeground="#ffffff",
                                   command=self._play, padx=24, pady=8, state="disabled")
        self.play_btn.pack(side="left", padx=4)

        self.stop_btn = tk.Button(ctrl_row, text="Stop", font=("Courier", 13, "bold"),
                                   bg="#c0392b", fg="#ffffff", relief="flat", bd=0,
                                   activebackground="#922b21", activeforeground="#ffffff",
                                   command=self._stop, padx=24, pady=8, state="disabled")
        self.stop_btn.pack(side="left", padx=4)

        self.progress_var = tk.DoubleVar(value=0)
        self.progress = ttk.Progressbar(self, variable=self.progress_var,
                                         maximum=100, length=560, mode="determinate")
        self.progress.pack(padx=20, pady=4)

        self.progress_label = tk.Label(self, text="0.0s / 0.0s",
                                        font=("Courier", 10), bg="#1a1a1a", fg="#555555")
        self.progress_label.pack()

        log_frame = tk.Frame(self, bg="#1a1a1a")
        log_frame.pack(fill="both", expand=True, padx=20, pady=8)

        tk.Label(log_frame, text="Log", font=("Courier", 10),
                 bg="#1a1a1a", fg="#555555").pack(anchor="w")
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

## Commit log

2026-06-25 Journal Entries 3 & 4, Finished First Draft of PCB
    [glockwork-orange.kicad_pcb, glockwork-orange.kicad_sch]
2026-06-27 Journal Entry Five, Added PCB .step
2026-06-27 Final Design Journal Entry (6), Added All Reqd Files To Submit.
    [BOM.csv, arduino_mega_2560.step, glockenspiel_mesh.step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]
